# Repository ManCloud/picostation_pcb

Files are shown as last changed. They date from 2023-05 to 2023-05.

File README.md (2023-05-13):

# picostation_pcb

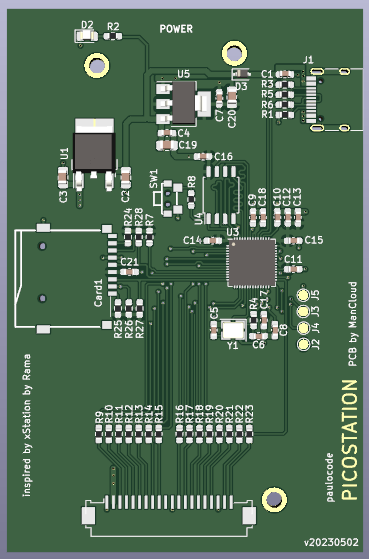
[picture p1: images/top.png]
PCB
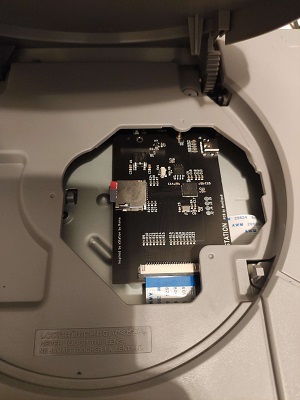
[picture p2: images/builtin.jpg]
builtin
 

This is my adaption of the PicoStation PCB for [paulocode](https://github.com/paulocode)s [PicoStation](https://github.com/paulocode/picostation).  
This layout was made to be completely purchaseable by JLCPCB therefore all partsnumbers etc. are included in the Project.

---

## NOTICE ##
for this board to properly work the crystal-wait time needs to be extended.  

For this you need to add the follwing lines in CmakeLists.txt under "add_executable(picostation)" :

>target_compile_definitions(  
>picostation PUBLIC  
>PICO_XOSC_STARTUP_DELAY_MULTIPLIER=64  
>) 

---

 - The FFC cable is the same one that comes with an Xstation

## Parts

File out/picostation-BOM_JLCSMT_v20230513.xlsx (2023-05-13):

Comment | Designator | Footprint | JLCPCB Part #（optional）
2.2k | R29,R2 | R_0603_1608Metric_Pad0.98x0.95mm_HandSolder | C4190
LED | D1,D2 | LED_0805_2012Metric_Pad1.15x1.40mm_HandSolder | C84256
10k | R28,R24,R7,R27,R26,R25,R30 | R_0603_1608Metric_Pad0.98x0.95mm_HandSolder | C25804
100n | C16,C8,C9,C17,C13,C18,C15,C14,C11 | C_0603_1608Metric_Pad1.08x0.95mm_HandSolder | C14663
100R | R12,R23,R18,R13,R10,R9,R20,R14,R21,R11,R15,R22,R17,R19 | R_0603_1608Metric_Pad0.98x0.95mm_HandSolder | C22775
47R | R16 | R_0603_1608Metric_Pad0.98x0.95mm_HandSolder | C23182
1u | C4,C21,C10,C12,C7 | C_0603_1608Metric_Pad1.08x0.95mm_HandSolder | C15849
10u | C19,C2,C3,C20 | C_0805_2012Metric_Pad1.18x1.45mm_HandSolder | C15850
1k | R8,R4 | R_0603_1608Metric_Pad0.98x0.95mm_HandSolder | C21190
5k1 | R3,R1 | R_0603_1608Metric_Pad0.98x0.95mm_HandSolder | C23186
AMS1117-3.3 | U5 | SOT-223-3_TabPin2 | C6186
Conn_01x20 | J6 | Molex_200528-0200_1x20-1MP_P1.00mm_Horizontal | C2914079
12 Mhz | Y1 | Crystal_SMD_3225-4Pin_3.2x2.5mm | C9002
USB_C_Receptacle_USB2.0 | J1 | USB_C_Receptacle_HRO_TYPE-C-31-M-12 | C2765186
LM78M05_TO252 | U1 | TO-252-2 | C58069
W25Q16JVSSIQ | U4 | SOIC-8_5.23x5.23mm_P1.27mm | C131025
BOOT | SW1 | SW-SMD_TS24CA | C393942
4.7u | C1 | C_0603_1608Metric_Pad1.08x0.95mm_HandSolder | C19666
27 | R5,R6 | R_0603_1608Metric_Pad0.98x0.95mm_HandSolder | C25190
30p | C5,C6 | C_0603_1608Metric_Pad1.08x0.95mm_HandSolder | C1658
TF-01A | Card1 | TF-SMD_TF-01A | C91145
1N5819WS | D3 | D_SOD-323 | C191023
RP2040 | U3 | RP2040-QFN-56 | C2040

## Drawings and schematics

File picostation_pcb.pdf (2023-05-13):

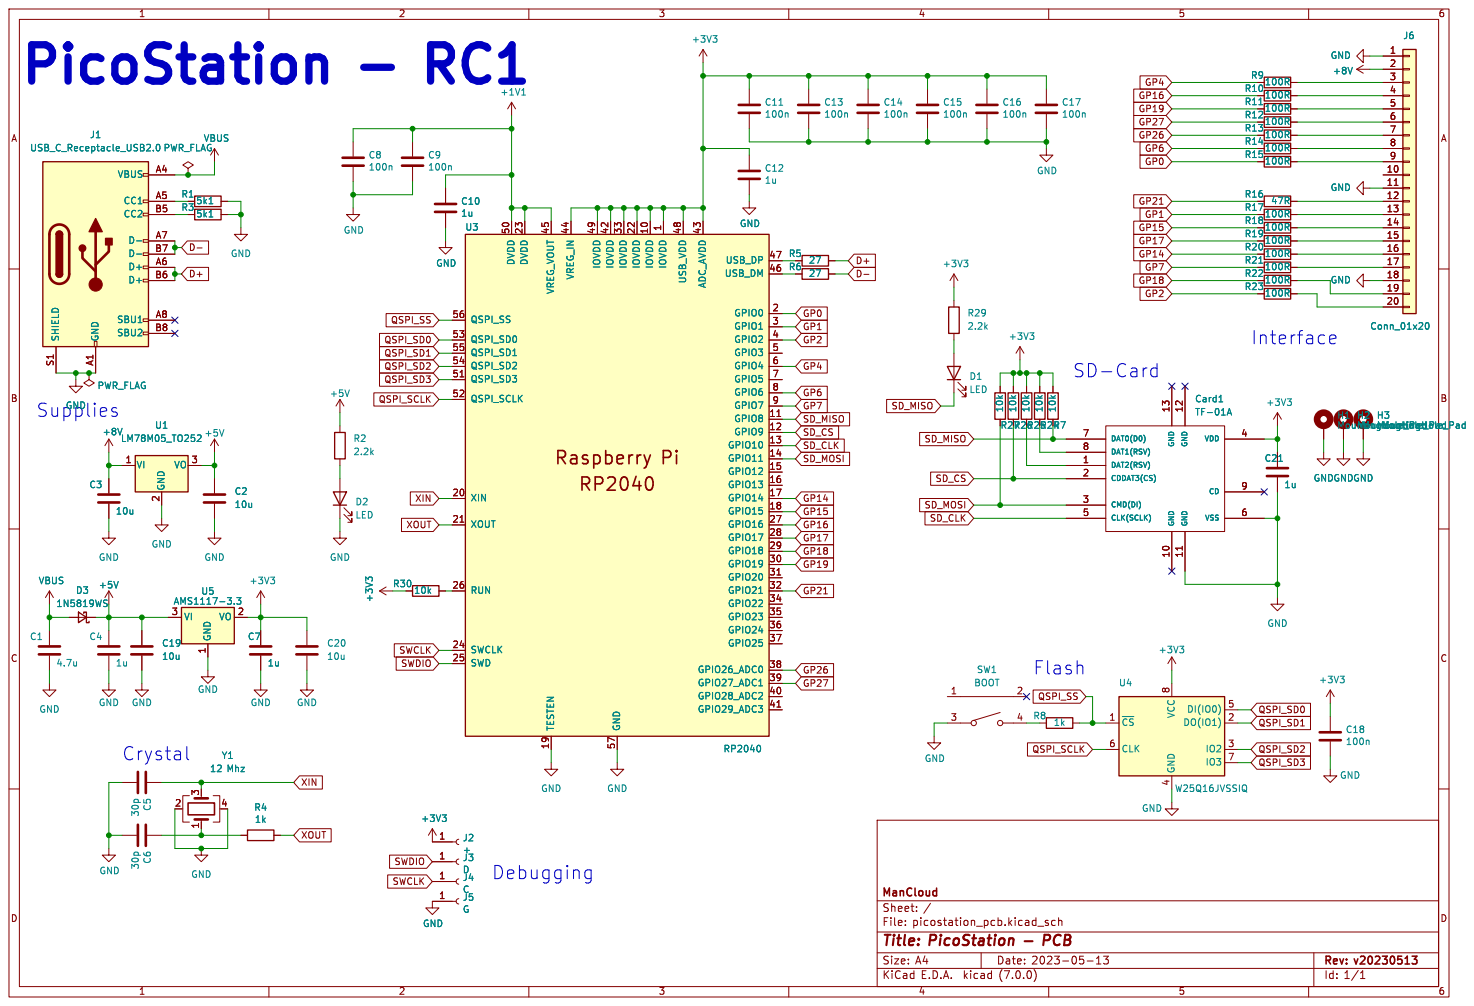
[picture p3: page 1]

1 IOVDD 10 GPIO8 11 GPIO9 12 GPIO10 13 GPIO11 14 GPIO12 15 GPIO13 16 GPIO14 17 GPIO15 18 TESTEN 19 GPIO0 2 XIN 20 XOUT 21 IOVDD 22 DVDD 23 SWCLK 24 SWD 25 RUN 26 GPIO16 27 GPIO17 28 GPIO18 29 GPIO1 3 GPIO19 30 GPIO20 31 GPIO21 32 IOVDD 33 GPIO22 34 GPIO23 35 GPIO24 36 GPIO25 37 GPIO26_ADC0 38 GPIO27_ADC1 39 GPIO2 4 GPIO28_ADC2 40 GPIO29_ADC3 41 IOVDD 42 ADC_AVDD 43 VREG_IN 44 VREG_VOUT 45 USB_DM 46 USB_DP 47 USB_VDD 48 IOVDD 49 GPIO3 5 DVDD 50 QSPI_SD3 51 QSPI_SCLK 52 QSPI_SD0 53 QSPI_SD2 54 QSPI_SD1 55 QSPI_SS 56 GND 57 GPIO4 6 GPIO5 7 GPIO6 8 GPIO7 9 U3 RP2040 C1

1 IOVDD 10 GPIO8 11 GPIO9 12 GPIO10 13 GPIO11 14 GPIO12 15 GPIO13 16 GPIO14 17 GPIO15 18 TESTEN 19 GPIO0 2 XIN 20 XOUT 21 IOVDD 22 DVDD 23 SWCLK 24 SWD 25 RUN 26 GPIO16 27 GPIO17 28 GPIO18 29 GPIO1 3 GPIO19 30 GPIO20 31 GPIO21 32 IOVDD 33 GPIO22 34 GPIO23 35 GPIO24 36 GPIO25 37 GPIO26_ADC0 38 GPIO27_ADC1 39 GPIO2 4 GPIO28_ADC2 40 GPIO29_ADC3 41 IOVDD 42 ADC_AVDD 43 VREG_IN 44 VREG_VOUT 45 USB_DM 46 USB_DP 47 USB_VDD 48 IOVDD 49 GPIO3 5 DVDD 50 QSPI_SD3 51 QSPI_SCLK 52 QSPI_SD0 53 QSPI_SD2 54 QSPI_SD1 55 QSPI_SS 56 GND 57 GPIO4 6 GPIO5 7 GPIO6 8 GPIO7 9 GND

Id: 1/1 Title: PicoStation - PCB

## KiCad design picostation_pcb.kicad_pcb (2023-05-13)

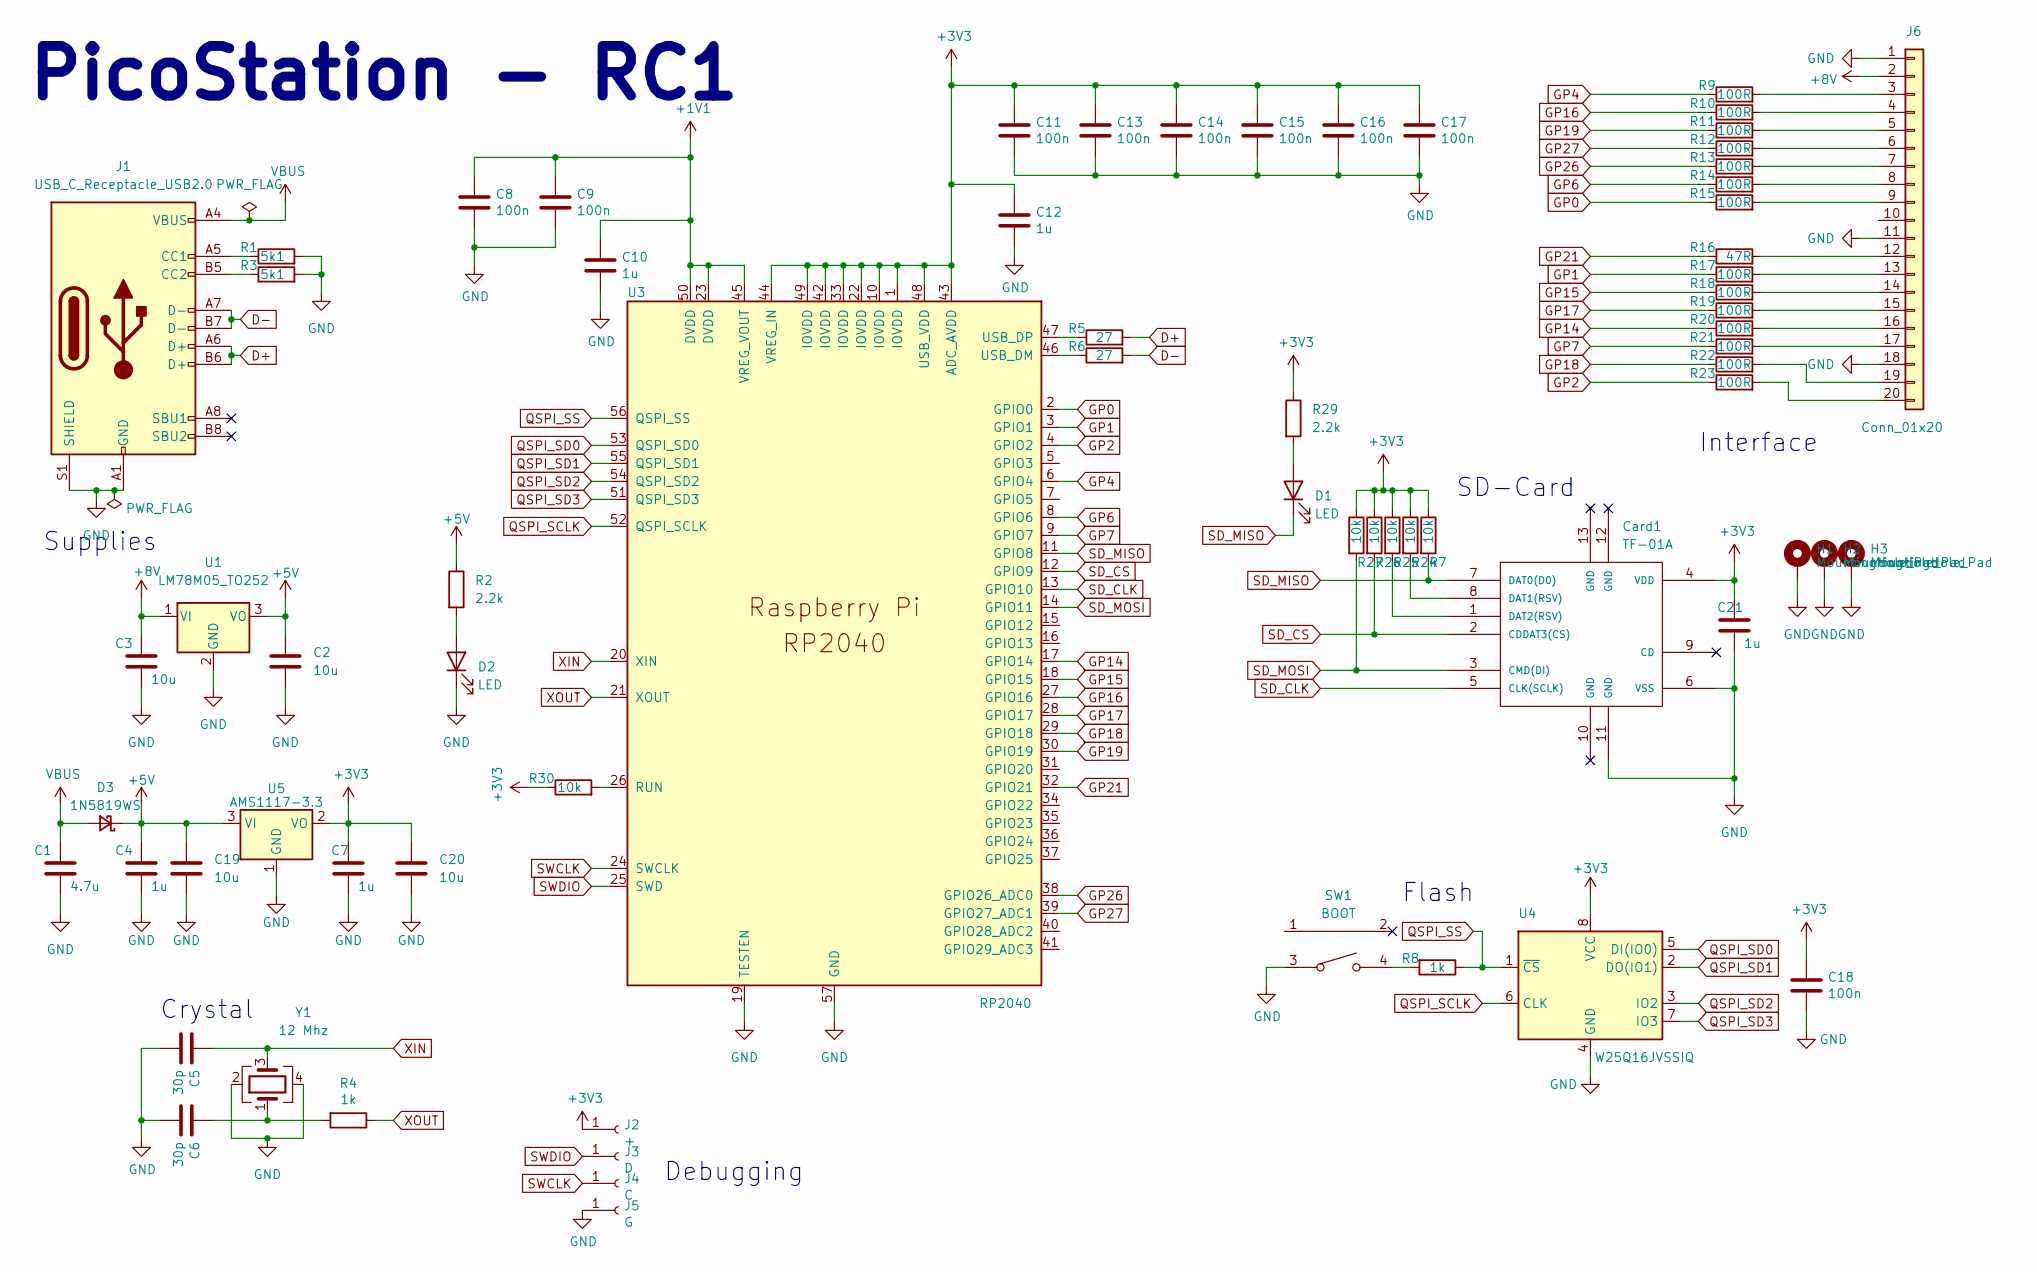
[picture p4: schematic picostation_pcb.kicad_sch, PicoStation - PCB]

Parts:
C1: 4.7u; C_0603_1608Metric_Pad1.08x0.95mm_HandSolder; LCSC C23733
C2, C3, C19, C20: 10u; C_0805_2012Metric_Pad1.18x1.45mm_HandSolder; LCSC C15850
C4, C7, C10, C12, C21: 1u; C_0603_1608Metric_Pad1.08x0.95mm_HandSolder; LCSC C52923
C5, C6: 30p; C_0603_1608Metric_Pad1.08x0.95mm_HandSolder; LCSC C1570
C8, C9, C11, C13, C14, C15, C16, C17, C18: 100n; C_0603_1608Metric_Pad1.08x0.95mm_HandSolder; LCSC C1525
Card1: TF-01A; TF-SMD_TF-01A; LCSC C91145
D1, D2: LED; LED_0805_2012Metric_Pad1.15x1.40mm_HandSolder
D3: 1N5819WS; D_SOD-323; LCSC C191023
H1, H2, H3: MountingHole_Pad; MountingHole_2.2mm_M2_DIN965_Pad
J1: USB_C_Receptacle_USB2.0; USB_C_Receptacle_HRO_TYPE-C-31-M-12; LCSC C2765186
J2: +; TestPoint_Pad_D1.5mm
J3: D; TestPoint_Pad_D1.5mm
J4: C; TestPoint_Pad_D1.5mm
J5: G; TestPoint_Pad_D1.5mm
J6: Conn_01x20; Molex_200528-0200_1x20-1MP_P1.00mm_Horizontal
R1, R3: 5k1; R_0603_1608Metric_Pad0.98x0.95mm_HandSolder
R2, R29: 2.2k; R_0603_1608Metric_Pad0.98x0.95mm_HandSolder
R4, R8: 1k; R_0603_1608Metric_Pad0.98x0.95mm_HandSolder; LCSC C11702
R5, R6: 27; R_0603_1608Metric_Pad0.98x0.95mm_HandSolder
R7, R24, R25, R26, R27, R30: 10k; R_0603_1608Metric_Pad0.98x0.95mm_HandSolder
R9, R10, R11, R12, R13, R14, R15, R17, R18, R19, R20, R21, R22, R23: 100R; R_0603_1608Metric_Pad0.98x0.95mm_HandSolder
R16: 47R; R_0603_1608Metric_Pad0.98x0.95mm_HandSolder
SW1: BOOT; SW-SMD_TS24CA; LCSC C393942
U1: LM78M05_TO252; TO-252-2
U3: RP2040; RP2040-QFN-56; LCSC C2040
U4: W25Q16JVSSIQ; SOIC-8_5.23x5.23mm_P1.27mm; LCSC C131025
U5: AMS1117-3.3; SOT-223-3_TabPin2; LCSC C6186
Y1: 12 Mhz; Crystal_SMD_3225-4Pin_3.2x2.5mm; LCSC C9002

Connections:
+1V1: C8.1, C9.1, C10.1, U3.23 (DVDD), U3.45 (VREG_VOUT), U3.50 (DVDD)
+3V3: C7.1, C11.1, C12.1, C13.1, C14.1, C15.1, C16.1, C17.1, C18.1, C20.1, C21.1, Card1.4 (VDD), J2.1, R7.1, R24.1, R25.1, R26.1, R27.1, R29.1, R30.1, U3.1 (IOVDD), U3.10 (IOVDD), U3.22 (IOVDD), U3.33 (IOVDD), U3.42 (IOVDD), U3.43 (ADC_AVDD), U3.44 (VREG_IN), U3.48 (USB_VDD), U3.49 (IOVDD), U4.8 (VCC), U5.2 (VO); also elsewhere on the board
+5V: C2.1, C4.1, C19.1, D3.1 (K), R2.1, U1.3 (VO), U5.3 (VI)
+8V: C3.1, J6.2, U1.1 (VI)
D+: J1.A6 (D+), J1.B6 (D+), R5.2
D-: J1.A7 (D-), J1.B7 (D-), R6.2
GND: C1.1, C2.2, C3.2, C4.2, C5.2, C6.2, C7.2, C8.2, C9.2, C10.2, C11.2, C12.2, C13.2, C14.2, C15.2, C16.2, C17.2, C18.2, C19.2, C20.2, C21.2, Card1.6 (VSS), Card1.11 (GND), D2.1 (K), H1.1, H2.1, H3.1, J1.A1 (GND), J1.A12 (GND), J1.B1 (GND), J1.B12 (GND), J1.S1 (SHIELD), J5.1, J6.1, J6.11, J6.18, R1.2, R3.2, SW1.3, U1.2 (GND), U3.19 (TESTEN), U3.57 (GND), U4.4 (GND), U5.1 (GND), Y1.2, Y1.4
GP0: R15.1, U3.2 (GPIO0)
GP1: R17.1, U3.3 (GPIO1)
GP2: R23.1, U3.4 (GPIO2)
GP4: R9.1, U3.6 (GPIO4)
GP6: R14.1, U3.8 (GPIO6)
GP7: R21.1, U3.9 (GPIO7)
GP14: R20.1, U3.17 (GPIO14)
GP15: R18.1, U3.18 (GPIO15)
GP16: R10.1, U3.27 (GPIO16)
GP17: R19.1, U3.28 (GPIO17)
GP18: R22.1, U3.29 (GPIO18)
GP19: R11.1, U3.30 (GPIO19)
GP21: R16.1, U3.32 (GPIO21)
GP26: R13.1, U3.38 (GPIO26_ADC0)
GP27: R12.1, U3.39 (GPIO27_ADC1)
unnamed: C6.1, R4.2, Y1.1
unnamed: Card1.8 (DAT1(RSV)), R24.2
unnamed: Card1.1 (DAT2(RSV)), R25.2
unnamed: D1.2 (A), R29.2
unnamed: D2.2 (A), R2.2
unnamed: J1.A5 (CC1), R1.1
unnamed: J1.B5 (CC2), R3.1
unnamed: J6.3, R9.2
unnamed: J6.4, R10.2
unnamed: J6.5, R11.2
unnamed: J6.6, R12.2
unnamed: J6.7, R13.2
unnamed: J6.8, R14.2
unnamed: J6.9, R15.2
unnamed: J6.12, R16.2
unnamed: J6.13, R17.2
unnamed: J6.14, R18.2
unnamed: J6.15, R19.2
unnamed: J6.16, R20.2
unnamed: J6.17, R21.2
unnamed: J6.19, R22.2
unnamed: J6.20, R23.2
unnamed: R8.2, SW1.4
unnamed: R30.2, U3.26 (RUN)
unnamed: R6.1, U3.46 (USB_DM)
unnamed: R5.1, U3.47 (USB_DP)
QSPI_SCLK: U3.52 (QSPI_SCLK), U4.6 (CLK)
QSPI_SD0: U3.53 (QSPI_SD0), U4.5 (DI(IO0))
QSPI_SD1: U3.55 (QSPI_SD1), U4.2 (DO(IO1))
QSPI_SD2: U3.54 (QSPI_SD2), U4.3 (IO2)
QSPI_SD3: U3.51 (QSPI_SD3), U4.7 (IO3)
QSPI_SS: R8.1, U3.56 (QSPI_SS), U4.1 (~CS)
SD_CLK: Card1.5 (CLK(SCLK)), U3.13 (GPIO10); also elsewhere on the board
SD_CS: Card1.2 (CDDAT3(CS)), R26.2, U3.12 (GPIO9)
SD_MISO: Card1.7 (DAT0(D0)), D1.1 (K), R7.2, U3.11 (GPIO8)
SD_MOSI: Card1.3 (CMD(DI)), R27.2, U3.14 (GPIO11)
SWCLK: J4.1, U3.24 (SWCLK)
SWDIO: J3.1, U3.25 (SWD)
VBUS: C1.2, D3.2 (A), J1.A4 (VBUS), J1.A9 (VBUS), J1.B4 (VBUS), J1.B9 (VBUS)
XIN: C5.1, U3.20 (XIN), Y1.3
XOUT: R4.1, U3.21 (XOUT)

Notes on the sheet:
SD-Card
Flash
Debugging
Interface
Crystal
Supplies
PicoStation - RC1

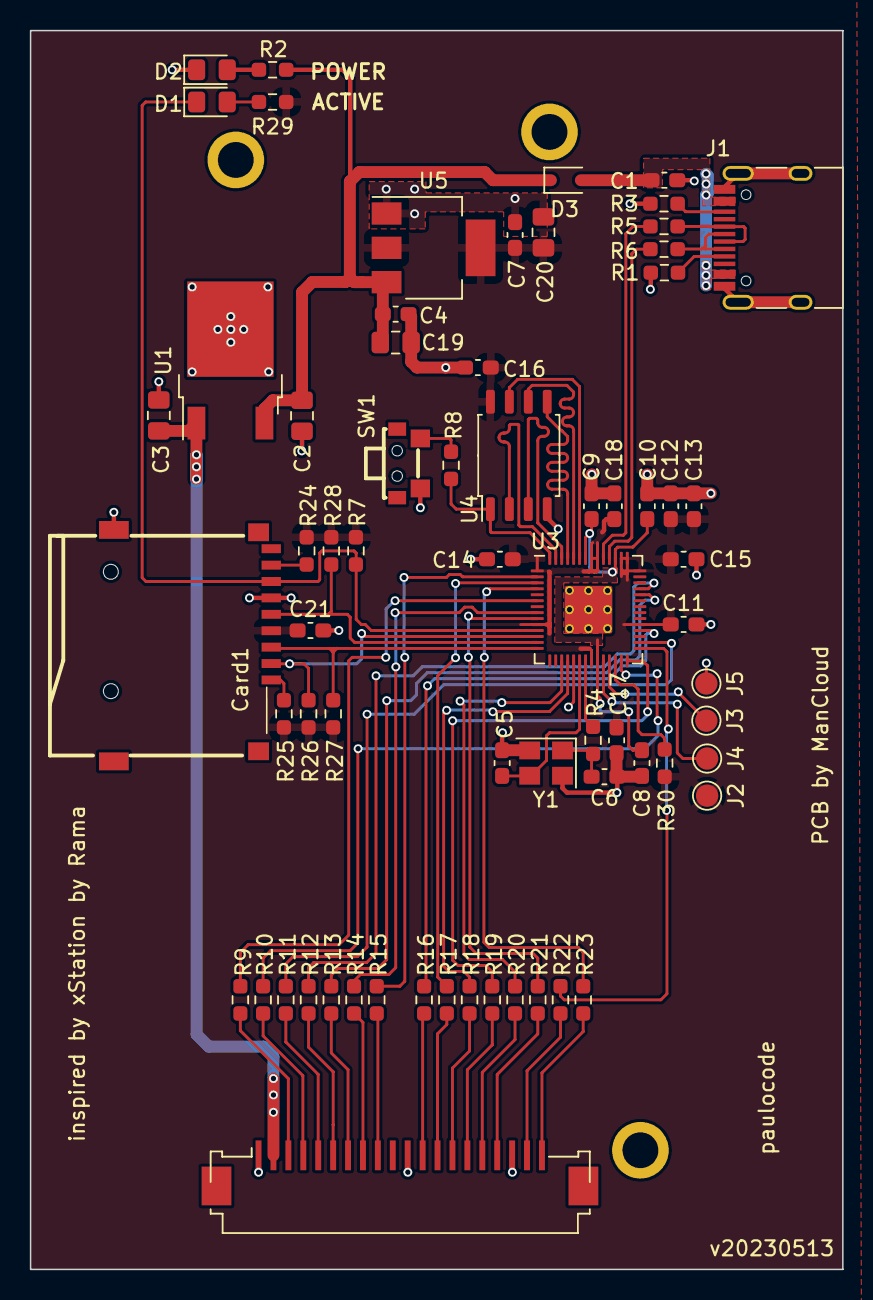
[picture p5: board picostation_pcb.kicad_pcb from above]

Board: 2 copper layers, 54.5 x 83.1 mm, 70 parts (0 on the bottom side), 63 nets.

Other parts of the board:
R28: 10k; R_0603_1608Metric_Pad0.98x0.95mm_HandSolder

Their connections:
+3V3: R28.1; also elsewhere on the board
SD_CLK: R28.2; also elsewhere on the board

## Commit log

2023-05-02 updated PCB
    [picostation_pcb.kicad_sch]
2023-05-13 Updated Board
    * removed SD-Cart Clock PullUp
    * added Active-LED (untested)
    * added Run PullUp
    [picostation_pcb.kicad_pcb, picostation_pcb.kicad_sch]
2023-05-13 added production files
    [picostation-BOM_JLCSMT_v20230513.xlsx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]
